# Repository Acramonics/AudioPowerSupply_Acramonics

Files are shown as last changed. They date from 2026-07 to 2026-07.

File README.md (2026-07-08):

Audio Power Supply
==================

(c) acramonics July 2026
------------------------

This audio power supply is a simple 15-0-15V supply using a 12-0-12V
transformer. It also provides a version with a 48V rail for phantom
power.

The design is very simple and based on ones from MKS, Jake Rothman and
Douglas Self.

If using a 12-0-12V transformer, then you only need small heatsinks
(as this will provide around 17-0-17V DC), but if using something like
a 15-0-15V transformer, you will need the specified Fischer SK104
heatsinks. The specified 2W resistor (R1) is overkill - around 0.25W
will be produced here, but it does get noticeably warm so the larger
resistor will guard against premature failure.

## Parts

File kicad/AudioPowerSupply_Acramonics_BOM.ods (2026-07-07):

Reference | Qty | Value | Footprint
C1,C2,C12,C13 | 4 | 1000uF 35V | Capacitor_THT:CP_Radial_D12.5mm_P5.00mm
C3,C4 | 2 | 100uF 100V | Capacitor_THT:CP_Radial_D12.5mm_P5.00mm
C5 | 1 | 220uF 100V | Capacitor_THT:CP_Radial_D12.5mm_P5.00mm
C6,C7,C8,C9,C10,C11 | 6 | 100nF | Capacitor_THT:C_Rect_L7.2mm_W3.0mm_P5.00mm_FKS2_FKP2_MKS2_MKP2
D1 | 1 | 1N4003 | Diode_THT:D_DO-41_SOD81_P10.16mm_Horizontal
D2,D3,D4,D5,D6,D7,D8,D9 | 8 | 1N4004 | Diode_THT:D_DO-41_SOD81_P10.16mm_Horizontal
J1 | 1 | Conn_01x02_Pin
J6 | 1 | GND 48V | Connector_Molex:Molex_KK-254_AE-6410-02A_1x02_P2.54mm_Vertical
J7,J8 | 2 | Conn_01x03_Pin | TerminalBlock_4Ucon:TerminalBlock_4Ucon_1x03_P3.50mm_Horizontal
R1 | 1 | 8K2 2W | Resistor_THT:R_Axial_DIN0414_L11.9mm_D4.5mm_P15.24mm_Horizontal
R2 | 1 | 240R | Resistor_THT:R_Axial_DIN0207_L6.3mm_D2.5mm_P10.16mm_Horizontal
T1 | 1 | 12-0-12V
U1 | 1 | LM7815_TO220 | Package_TO_SOT_THT:TO-220-3_Vertical
U2 | 1 | LM7915_TO220 | Package_TO_SOT_THT:TO-220-3_Vertical
U3 | 1 | LM317_TO-220 | Package_TO_SOT_THT:TO-220-3_Vertical
 | 3 |  | Heatsink_Fischer_SK104-STC-STIC_35x13mm_2xDrill2.5mm

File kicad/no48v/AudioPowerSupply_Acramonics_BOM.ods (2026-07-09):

Reference | Qty | Value | Footprint
C1,C2,C5,C6 | 4 | 1000uF 35V | Capacitor_THT:CP_Radial_D12.5mm_P5.00mm
C3,C4,C7,C8 | 4 | 100nF | Capacitor_THT:C_Rect_L7.2mm_W3.0mm_P5.00mm_FKS2_FKP2_MKS2_MKP2
C14 | 1 | 10nF | Capacitor_THT:C_Rect_L7.2mm_W3.0mm_P5.00mm_FKS2_FKP2_MKS2_MKP2
D1,D2,D3,D4 | 4 | 1N4004 | Diode_THT:D_DO-41_SOD81_P10.16mm_Horizontal
D10 | 1 | LED
J2 | 1 |  | TerminalBlock_Altech:Altech_AK100_1x04_P5.00mm
J3 | 1 |  | TerminalBlock_Altech:Altech_AK100_1x03_P5.00mm
J4 | 1 |  | Connector_Molex:Molex_KK-254_AE-6410-02A_1x02_P2.54mm_Vertical
R3 | 1 | 3K6 1W | Resistor_THT:R_Axial_DIN0414_L11.9mm_D4.5mm_P15.24mm_Horizontal
R4 | 1 | 1K | Resistor_THT:R_Axial_DIN0207_L6.3mm_D2.5mm_P10.16mm_Horizontal
T1 | 1 | 12-0-12V
U1 | 1 | LM7815_TO220 | Package_TO_SOT_THT:TO-220-3_Vertical
U2 | 1 | LM7915_TO220 | Package_TO_SOT_THT:TO-220-3_Vertical

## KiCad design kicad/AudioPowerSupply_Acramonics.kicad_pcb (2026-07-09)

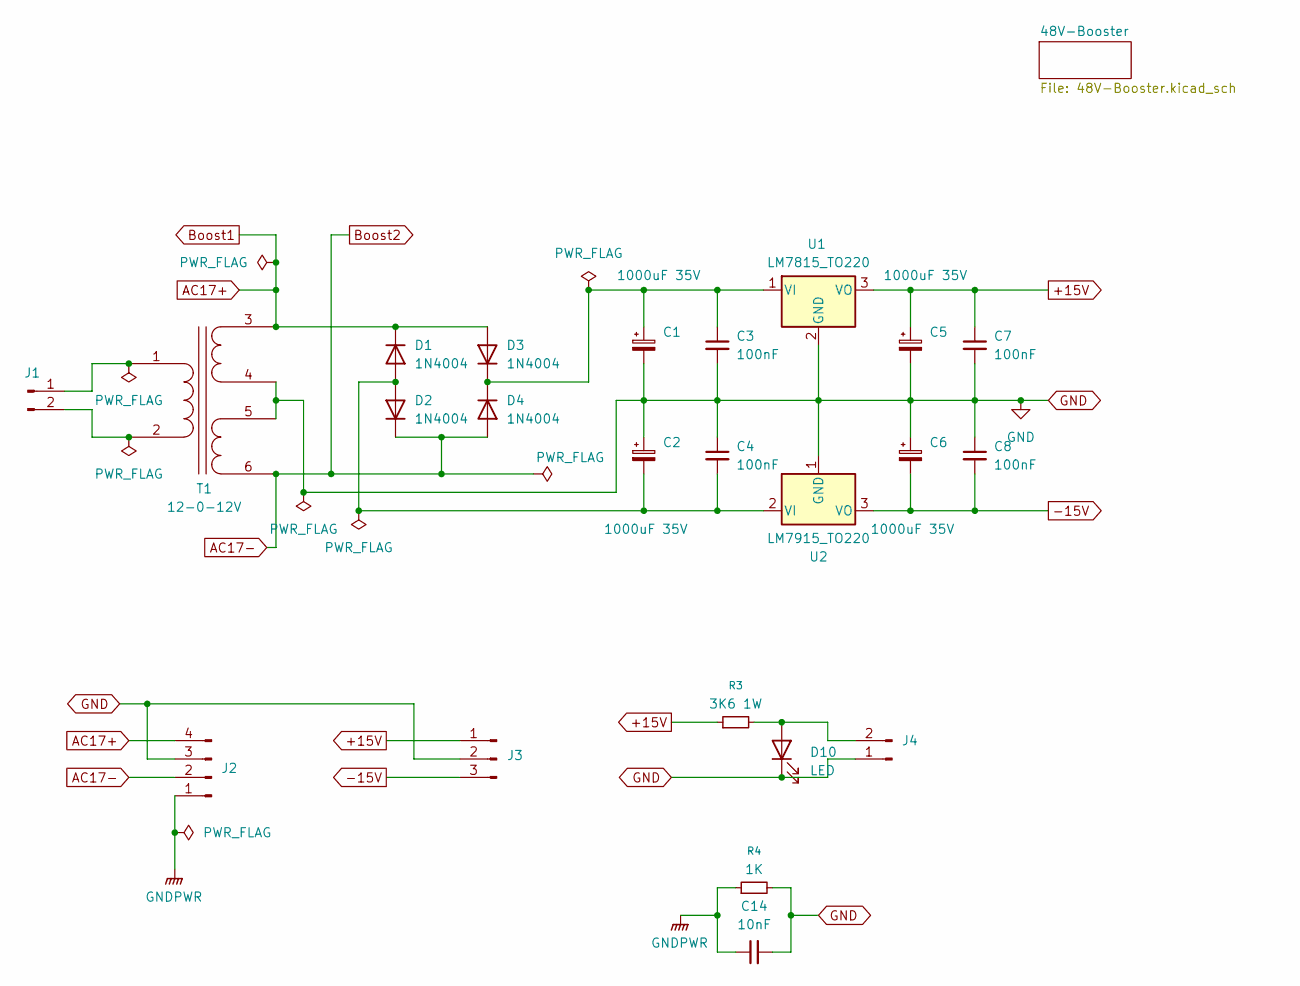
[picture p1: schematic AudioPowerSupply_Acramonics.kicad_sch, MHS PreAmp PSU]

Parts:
C1, C2, C5, C6: 1000uF 35V; CP_Radial_D12.5mm_P5.00mm
C3, C4, C7, C8: 100nF; C_Rect_L7.2mm_W3.0mm_P5.00mm_FKS2_FKP2_MKS2_MKP2
C14: 10nF; C_Rect_L7.2mm_W3.0mm_P5.00mm_FKS2_FKP2_MKS2_MKP2
D1, D2, D3, D4: 1N4004; D_DO-41_SOD81_P10.16mm_Horizontal
D10: LED
J1: (no value)
J2: Conn_01x04_Pin; Altech_AK100_1x04_P5.00mm
J3: Altech_AK100_1x03_P5.00mm
J4: Molex_KK-254_AE-6410-02A_1x02_P2.54mm_Vertical
R3: 3K6 1W; R_Axial_DIN0414_L11.9mm_D4.5mm_P15.24mm_Horizontal
R4: 1K; R_Axial_DIN0207_L6.3mm_D2.5mm_P10.16mm_Horizontal
T1: 12-0-12V
U1: LM7815_TO220; TO-220-3_Vertical
U2: LM7915_TO220; TO-220-3_Vertical

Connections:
+15V: C5.1, C7.1, J3.1, R3.1, U1.3 (VO)
-15V: C6.2, C8.2, J3.3, U2.3 (VO)
AC17+: D1.1 (K), D3.2 (A), J2.4, T1.3 (SA); also elsewhere on the board
AC17-: D2.1 (K), D4.2 (A), J2.2, T1.6 (SD); also elsewhere on the board
GND: C1.2, C2.1, C3.2, C4.1, C5.2, C6.1, C7.2, C8.1, C14.2, D10.1 (K), J2.3, J3.2, J4.1, R4.2, T1.4 (SB), T1.5 (SC), U1.2 (GND), U2.1 (GND); also elsewhere on the board
GNDPWR: C14.1, J2.1, R4.1
unnamed: C2.2, C4.2, D1.2 (A), D2.2 (A), U2.2 (VI)
unnamed: C1.1, C3.1, D3.1 (K), D4.1 (K), U1.1 (VI)
unnamed: J1.1, T1.1 (AA)
unnamed: J1.2, T1.2 (AB)
unnamed: D10.2 (A), J4.2, R3.2

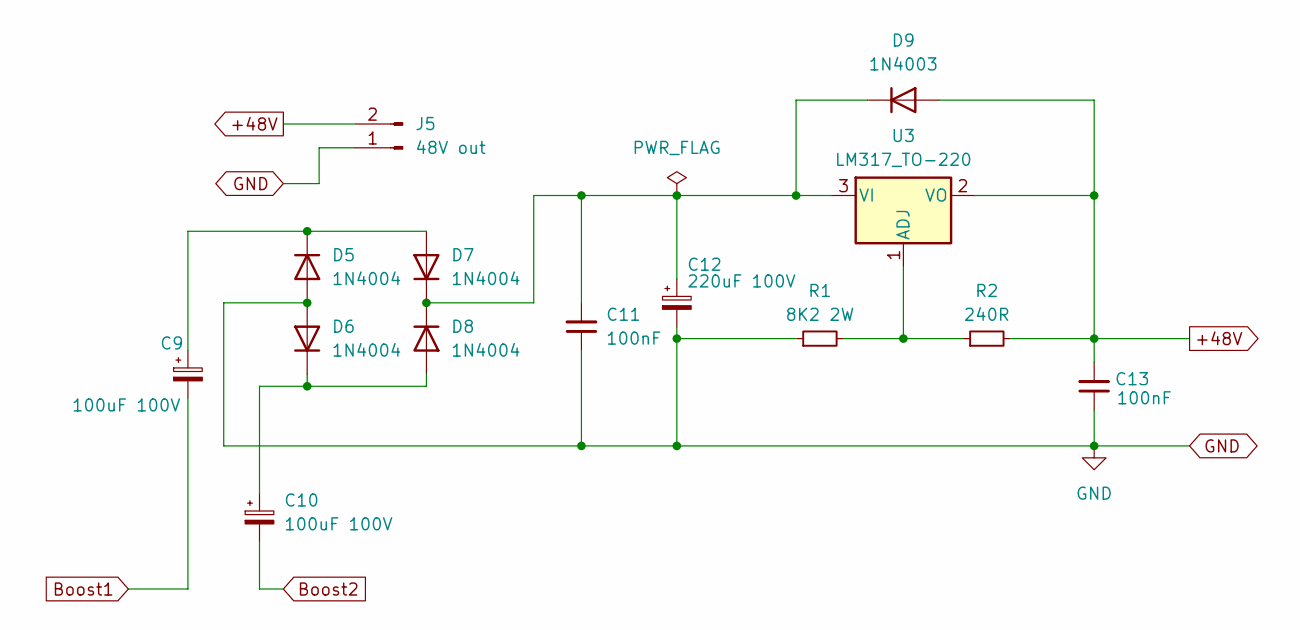
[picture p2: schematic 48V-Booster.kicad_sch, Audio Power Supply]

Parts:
C9, C10: 100uF 100V; CP_Radial_D12.5mm_P5.00mm
C11, C13: 100nF; C_Rect_L7.2mm_W3.0mm_P5.00mm_FKS2_FKP2_MKS2_MKP2
C12: 220uF 100V; CP_Radial_D12.5mm_P5.00mm
D5, D6, D7, D8: 1N4004; D_DO-41_SOD81_P10.16mm_Horizontal
D9: 1N4003; D_DO-41_SOD81_P10.16mm_Horizontal
J5: 48V out; Molex_KK-254_AE-6410-02A_1x02_P2.54mm_Vertical
R1: 8K2 2W; R_Axial_DIN0516_L15.5mm_D5.0mm_P25.40mm_Horizontal
R2: 240R; R_Axial_DIN0207_L6.3mm_D2.5mm_P10.16mm_Horizontal
U3: LM317_TO-220; TO-220-3_Vertical

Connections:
+48V: C13.2, D9.2 (A), J5.2, R2.2, U3.2 (VO)
AC17+: C9.2; also elsewhere on the board
AC17-: C10.2; also elsewhere on the board
GND: C11.1, C12.2, C13.1, D5.2 (A), D6.2 (A), J5.1, R1.1; also elsewhere on the board
unnamed: C9.1, D5.1 (K), D7.2 (A)
unnamed: C10.1, D6.1 (K), D8.2 (A)
unnamed: C11.2, C12.1, D7.1 (K), D8.1 (K), D9.1 (K), U3.3 (VI)
unnamed: R1.2, R2.1, U3.1 (ADJ)

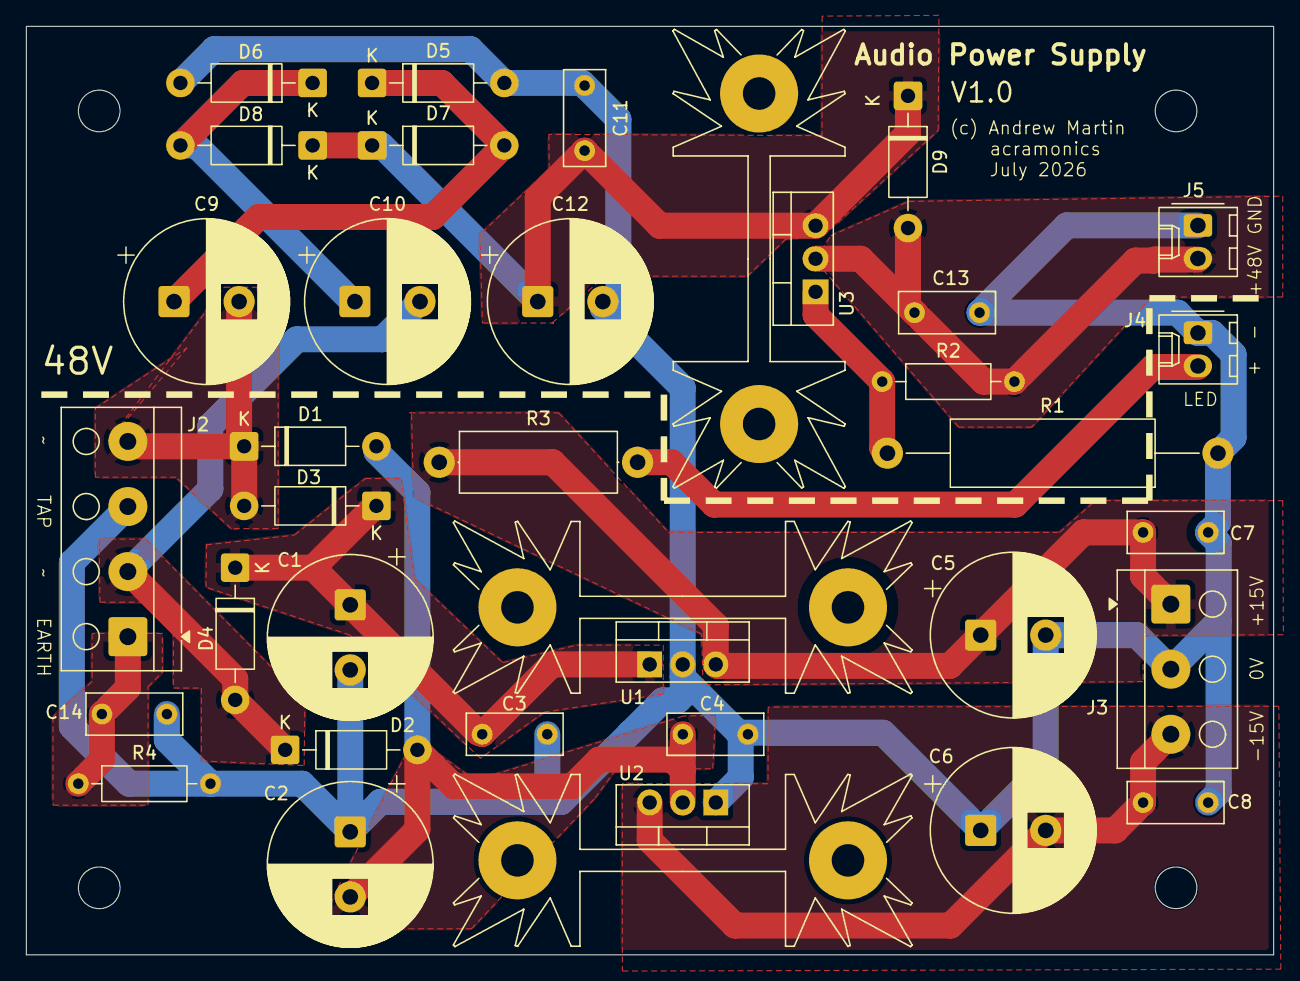
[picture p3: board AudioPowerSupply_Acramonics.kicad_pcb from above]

Board: 2 copper layers, 95.8 x 71.3 mm, 34 parts (0 on the bottom side), 14 nets.

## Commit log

2026-07-07 Added BOM
    [AudioPowerSupply_Acramonics_BOM.ods]
2026-07-07 Put 48V circuit on separate diagram
    [AudioPowerSupply_Acramonics.kicad_pcb, AudioPowerSupply_Acramonics.kicad_sch]
2026-07-08 Added booster schematic
    [48V-Booster.kicad_sch]
2026-07-08 Board done - needs added text
    [48V-Booster.kicad_sch, AudioPowerSupply_Acramonics.kicad_pcb, AudioPowerSupply_Acramonics.kicad_sch]
2026-07-08 Added text and updated readme
    [AudioPowerSupply_Acramonics.kicad_pcb]
2026-07-08 Added line to divide 48V section
    [AudioPowerSupply_Acramonics.kicad_pcb]
2026-07-09 Added scripts to generate non 48V version and a PCB and BOM for this
    [48V-Booster.kicad_sch, AudioPowerSupply_Acramonics.kicad_pcb, AudioPowerSupply_Acramonics.kicad_sch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]
2026-07-09 Added gerber and tweaked fills on full version
    [AudioPowerSupply_Acramonics.kicad_pcb]
